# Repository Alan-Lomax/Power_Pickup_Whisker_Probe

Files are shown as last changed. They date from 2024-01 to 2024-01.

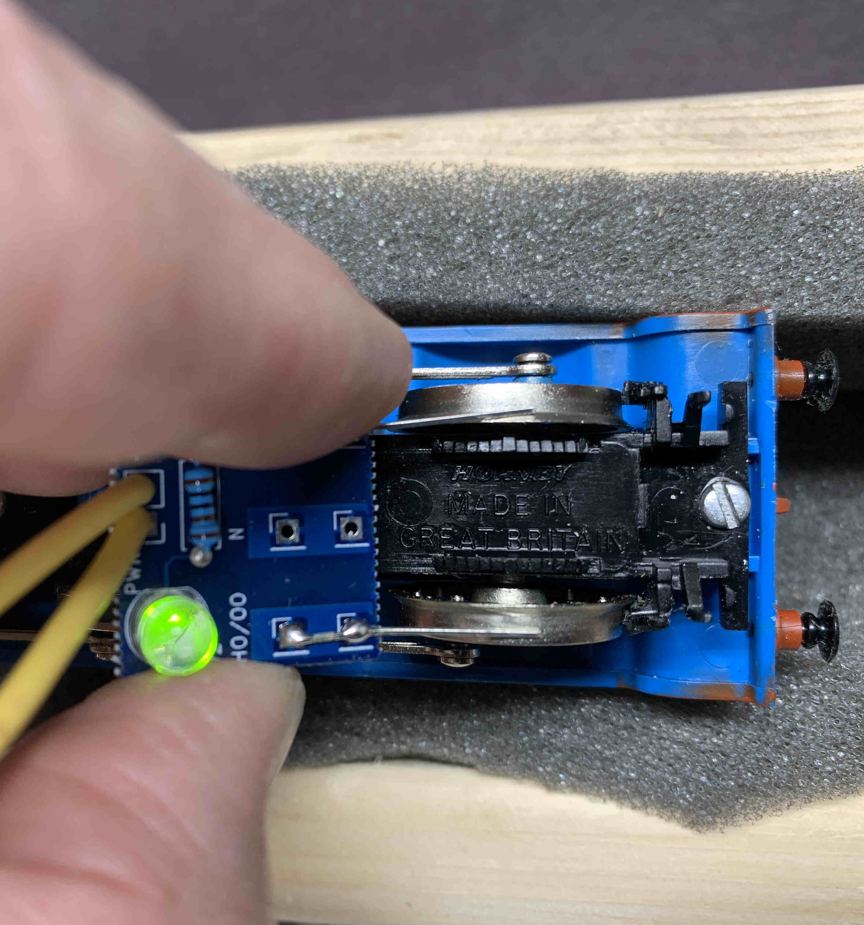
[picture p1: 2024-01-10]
Documentation/Photos/Figure 10f - Testing Pickups.jpg

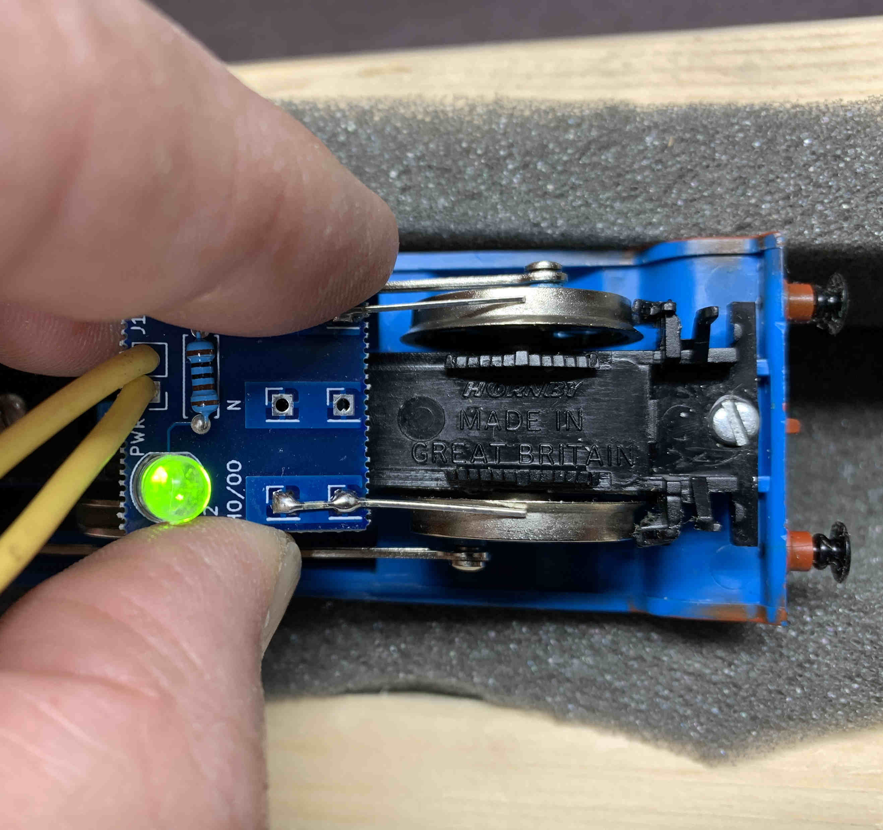
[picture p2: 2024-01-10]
Documentation/Photos/Figure 10e - Testing Pickups.jpg

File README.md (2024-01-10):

# Power Pickup Whisker Probe
Is a very small PCB board using only a couple of components (one LED and one resistor)
It is a simple voltage tester for use on the model railway.
Using the whiskers it can also be used to inject power to a specfic wheel set 
on a loco and thus used to detect loose, dirty, or ill fitting pickup contacts.

## Key Features
<Li>Reliable clear indication of power and polarity
<Li>Inexpensive and easy to build
<Li>DC or DCC operation
<Li>Test track, loco pickups, slow action DC motor switching

## Status of Development 
### Only one Prototype Version so Far

## Known Issues
<Li>None

## Thoughts for Improvement
<Li>Add a footprint for a terminal block

# The Panel Version
The PCB is sized less than 20mmm x 20 mm which means it can easily be panelized
in sets of 25. This makes the panelized PCB fit on a single 100mm x 100mm 
PCB which is the normal 'minimum size' for billing. 
Be Aware as the minimum board order quantity is 5 you would get 125 
Power Pickup Whisker Probe PCB's.

There is a seperate folder containing the Panelized version of the Gerbers.

As the individual PCB is small you could consider adding the 
Power Pickup Whisker Probe PCB to another PCB that you may be
ordering anyway.

# Be Aware
Normally all EDITS should be done to the 'single PCB' and then it be repanelized
To repanelize you start a new Kicad project (one with no contents)
and run a 'plug in' to panelize things. You will specfiy which other 
file has the PCB layout you want to panelize. 
You also set the number of rows (5) and collumns (5)
The only manual step needed is to add several straight edge to edge lines
(on the edge cut layer) to separate the individual test boards.
These will be intepreted as 'Vee-Cut' lines and allows separating the two PCBs easily.

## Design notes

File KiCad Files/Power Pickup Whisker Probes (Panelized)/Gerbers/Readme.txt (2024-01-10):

The panelized power pickup gerbers are a 5 x 5 array in 100mm x 100mm
With the minimum production qty of 5 PCB's that is 125 individual circuit boards
Boards have Vee Cut lines to make separation (de-panelizing) easier.

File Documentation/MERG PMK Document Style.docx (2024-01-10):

Potential Pocket Money Kit

January 2024

The Track Tester pocket money project PMP1 was first described, by Davy Dick, in the MERG Journal (2012 Vol 46 No. 3 p16-17). This kit while it was developed independently is similar but it also has whiskers for testing loco pickups.

Parts List

• PCB (Printed Circuit Board)

• One lead with a crocodile clip attached at each end

• One bi-colour LED

• One 1K resistor

There are many occasions when you may need to check if a particular section of track is receiving power.

Maybe -

• The power to a track section is switched by relays or switches.

• The wiring or connections to a piece of track is suspect.

• You want to check if you have wired a new piece of track with the polarity the

correct way round.

• You need to test if individual pickups on a Loco are working

• You need to test that a slow action point motor is getting power reversals as it should.

This simple PCB can do all of this with a minimum of parts. Of course, you could always check with a multimeter but these are inconvenient, bulky and awkward to use in tight situations.

With this little board, for rail checks you can use either the crocodile clips, the whiskers, or the contact points on the bottom of the PCB to illuminate the LED. If the LED lights Red or Green you have DC power with the colour indicating polarity. If the LED lights orange your track is receiving DCC power.

For testing loco pickups attach the crocodile leads to the track and touch the whiskers one to each wheel on a single axle. If the wheel pickups are working as they should be the loco motor will operate. You can then use the whiskers to apply side to side force in either direction to ensure pickups maintain contact with the wheels throughout the range of side-to-side motion. Repeat this on each axle that has pickups to give your loco a thorough checkup.

How it works

The circuit diagram is very simple. A bi-colour LED (light emitting diode) is connected across the track when the board's crocodile clips or the whiskers touch the rails. The 1k resistor is a current limiting resistor to ensure the track voltage does not result in excessive current that would destroy the LED. A bi-colour LED is simply two LEDs back-to-back and in the same LED package. So, if the track voltage is one polarity, the LED lights up in one colour (green for example), and if the track voltage is in the opposite polarity that same LED lights up a different colour (red for example). If the polarity is switching back and forth quickly (as in DCC) your eye perceives the blended colour.

Building Instructions

The components are inserted on the printed side of the PCB, and soldered on the other side. As there only a few parts strict order of assembly is not critical however the following sequence is recommended.

Fit the LED with the long lead inserted in the hole nearest the flats on the symbol. Note that with back-to-back diodes in the same package there is no ‘cathode lead’ or ‘anode lead’. The reason for setting the orientation is only to ensure the displayed colour shows consistently should you build several of these kits.

Ensure the LED is flush to the PCB and after soldering cut off both leads as close to the underside of the PCB as possible. IMPORTANT: We will be using the cut off leads as our whiskers in the next step.

Referring to Figure 6 use needle nose pliers put a 90 degree bend very close to one end in each lead. Insert the bent end into the PCB hole as indicated on the ‘Common’ set of pads. With the long end of the whisker roughly aligned solder the bent pin in place. Ensure the long end of the whisker lead goes over the center of the remaining hole (gently bending as needed) then solder the lead which is lying flat over the hole and extending past the edge of the board.

Depending on what gauge you are modelling (HO/OO or N) repeat this process for the second whisker using the appropriate set of holes.

Fit the resistor which can be inserted either way round.

Cut the crocodile lead in half, strip the ends of the “half leads” and solder them one at a time into the holes marked J1.

Lastly to avoid shorts if the board is laid on the track or other metalwork fit some insulation tape to one half of the back of the PCB (specifically under the resistor, LED and J1 part of the PCB. An alternative to tape is to apply hot glue from a glue gun.

Figures

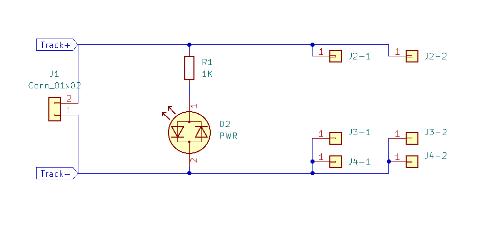
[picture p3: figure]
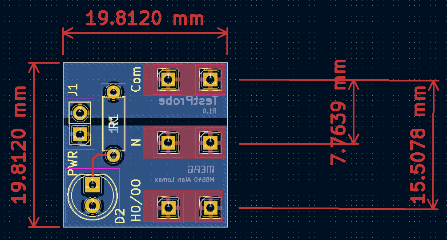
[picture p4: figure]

Figure 1: Schematic | Figure 2: Key Dimensions of PCB

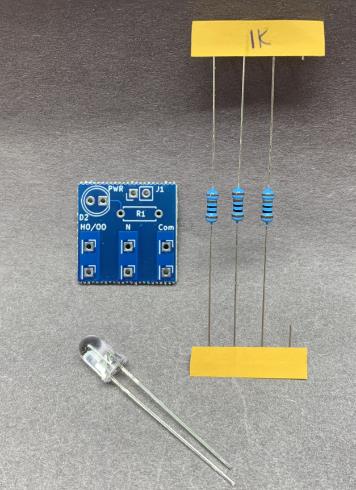
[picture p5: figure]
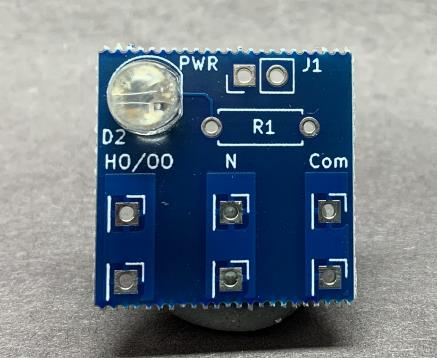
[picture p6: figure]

Figure 3: Key Parts (Only 1 Resistor needed of course) | Figure 4: LED Orientation LED oriented with Flat matching the symbol.

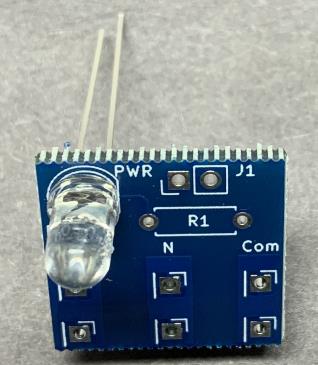
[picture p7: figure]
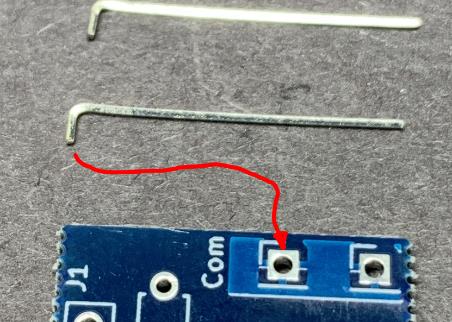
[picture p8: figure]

Figure 5: Showing the long lead is on the side with the Flat on a Bi-colour LED | Figure 6: First solder location of the first whisker

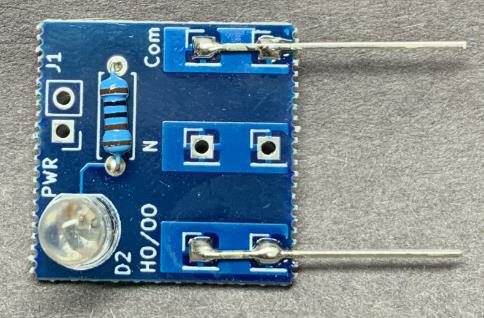
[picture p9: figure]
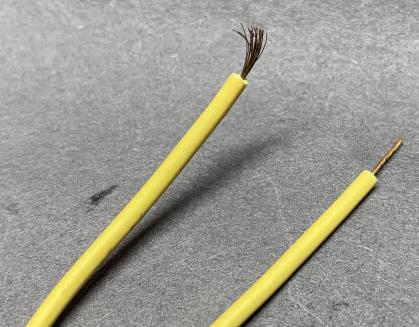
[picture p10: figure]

Figure 7: Whiskers aligned and Soldered, Components in Place | Figure 8: Leads stripped. A gentle twist of the strands (lower lead) makes inserting into the PCB easier and more importantly reduces the risk of an inadvertent short circuit from a stray strand.

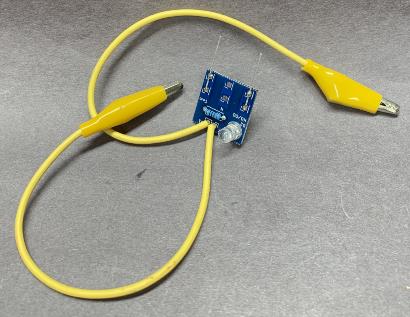
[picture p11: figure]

Figure 9: Fully Assembled and Ready to Use

# Usage Cases

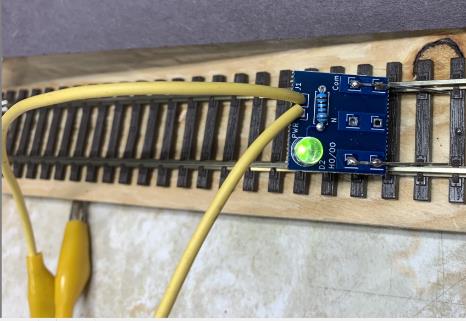
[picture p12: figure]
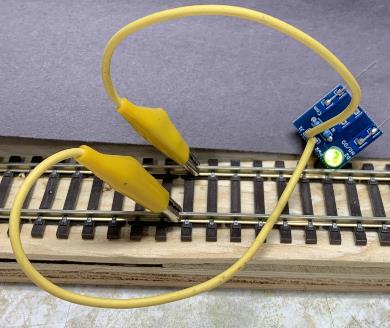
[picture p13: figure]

Figure 10a: Track power via the whiskers. Lower rail (The LED side) is positive green LED. | | Figure 10b: Alternate method using the crocodile clips.

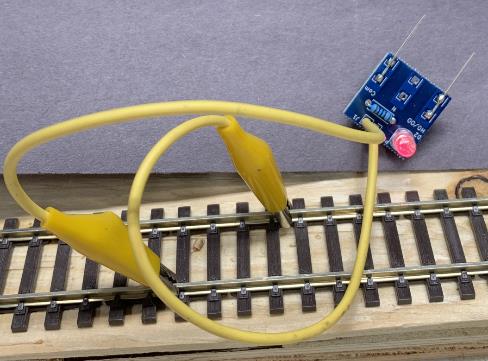
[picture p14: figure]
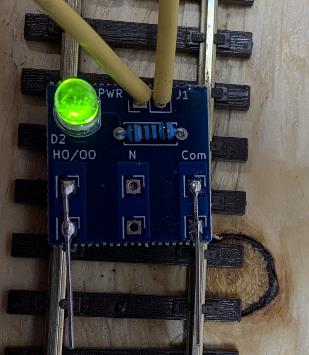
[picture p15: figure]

Figure 10c: Crocodile clips crossed over. Red LED indicates polarity is reversed (of course it is the leads that are actually reversed not the track voltage). | | Figure 10d: Alternate method – lay flat on the rails. Caution – Use only with whiskers in direction of track.

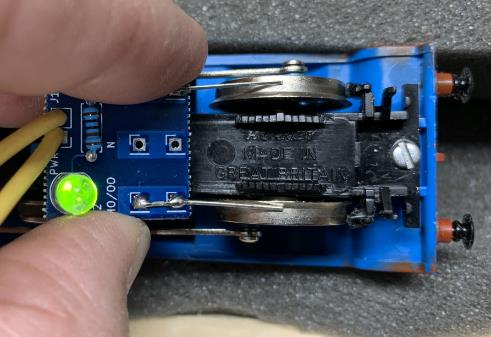
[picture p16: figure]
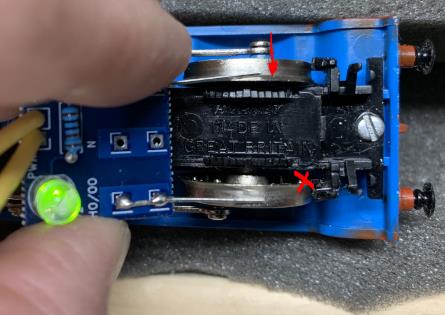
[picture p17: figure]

Figure 11a With crocodile clips on track use whiskers to apply power to a single wheel set. Wheels will turn if pickups are working correctly. Lateral force up on the lower flange reveals if the pickup on the upper wheel is breaking contact. As the motor keeps running these pickups are operating as expected. | Figure 11b Lateral force down opens up the gap as shown by X. The motor stops running but the LED indicates I still have power. The pickups on the side marked X need a slight adjustment.

Ideas for Variations:

It may be desirable in some situations to use terminal blocks instead of directly soldering the crocodile clips in place. At the moment the spacing of the PCB holes does not accommodate dropping in a terminal block so some customization will be required.

Using the LED leads for whiskers may not allow for enough lateral force for your application. It is possible to substitute 0.8 mm stainless steel piano wire (two pieces each 2 cm long). Note however that soldering of stainless steel requires a fit for purpose acid flux applied to the piano wire (at the end with the 90-degree bend plus half the remaining length). This much of the whisker is then tinned with solder. The flux must be cleaned off thoroughly before the whiskers are installed on the PCB. (If not the Acid could continue to work away potentially damaging the board)

Acknowledgements

Mike Walton of the Platelayers MRC in Ontario Canada who patiently explained his ‘snag report’ and the home-made whisker set up that he came up with to find that pesky loco pickup that only failed in a certain location of his layout.

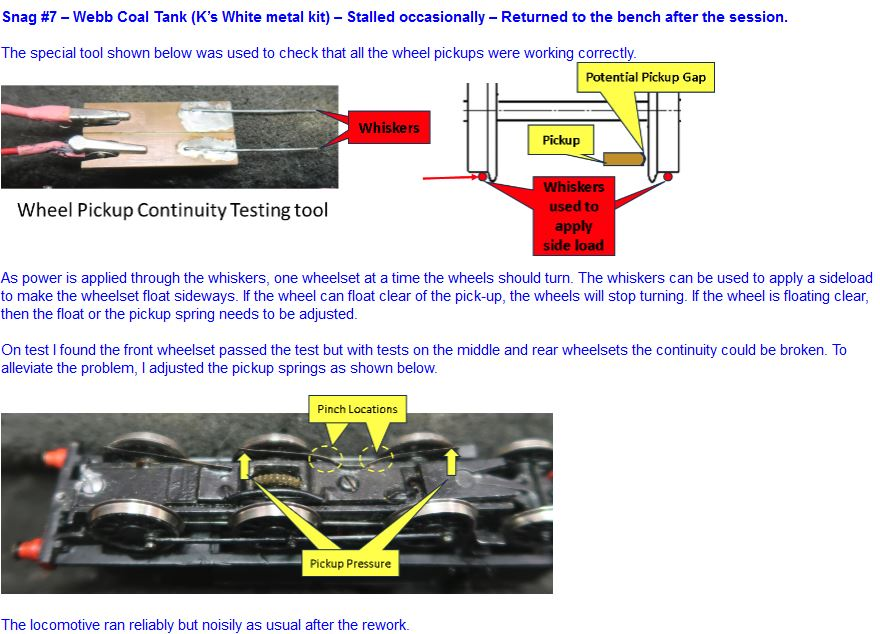
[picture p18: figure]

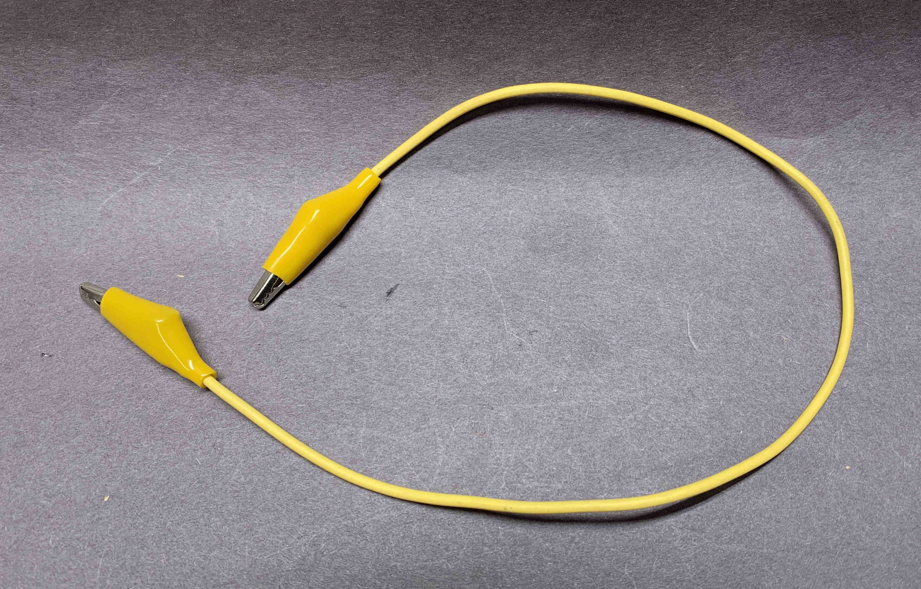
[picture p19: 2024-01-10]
Documentation/Photos/Figure 4 Single Alligator Clip.jpg

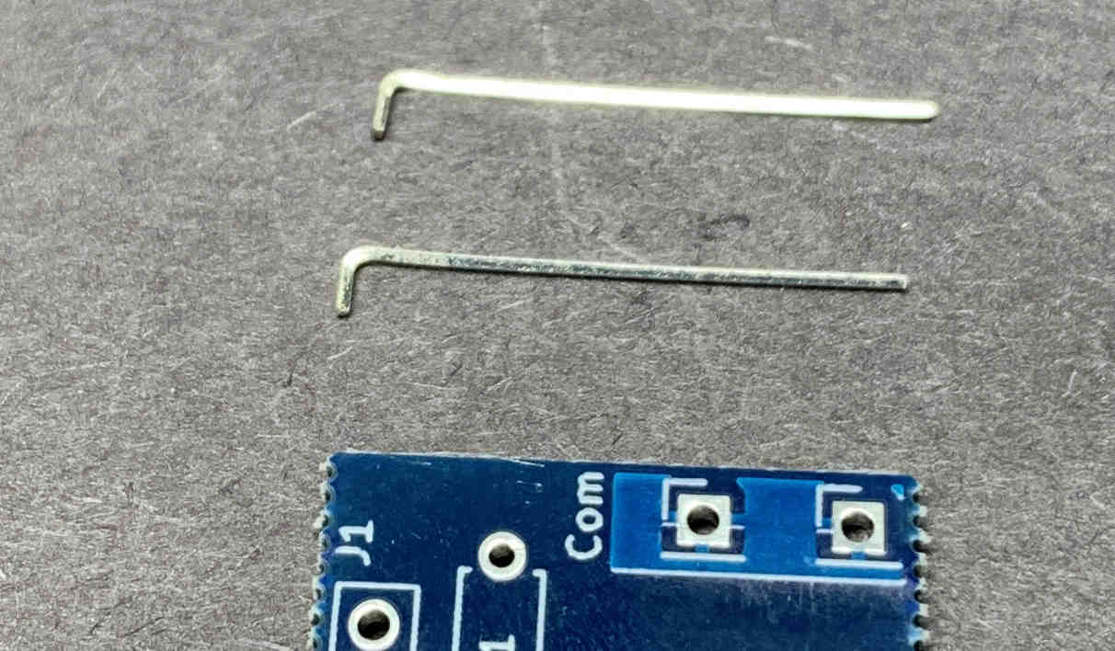
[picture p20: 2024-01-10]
Documentation/Photos/Figure 6 LED leads cutoff trimmed and bent.jpg

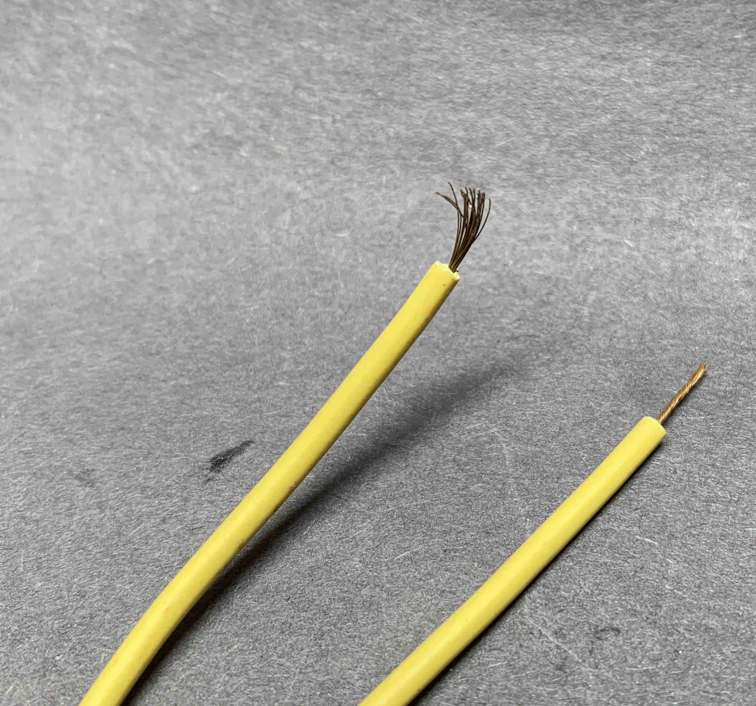
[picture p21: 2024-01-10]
Documentation/Photos/Figure 8 Importance of Twisting the ends.jpg

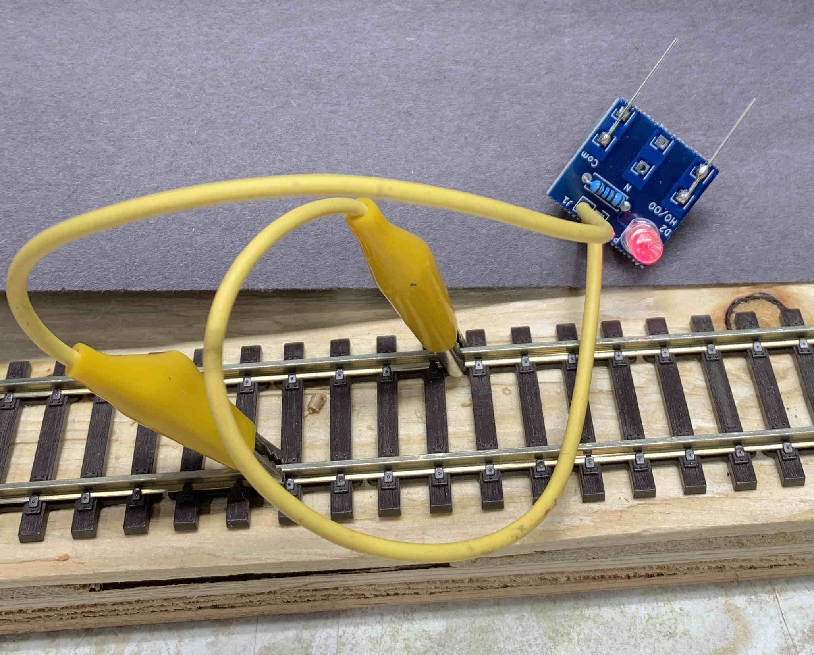
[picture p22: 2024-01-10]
Documentation/Photos/Figure 10c - Track Power.jpg

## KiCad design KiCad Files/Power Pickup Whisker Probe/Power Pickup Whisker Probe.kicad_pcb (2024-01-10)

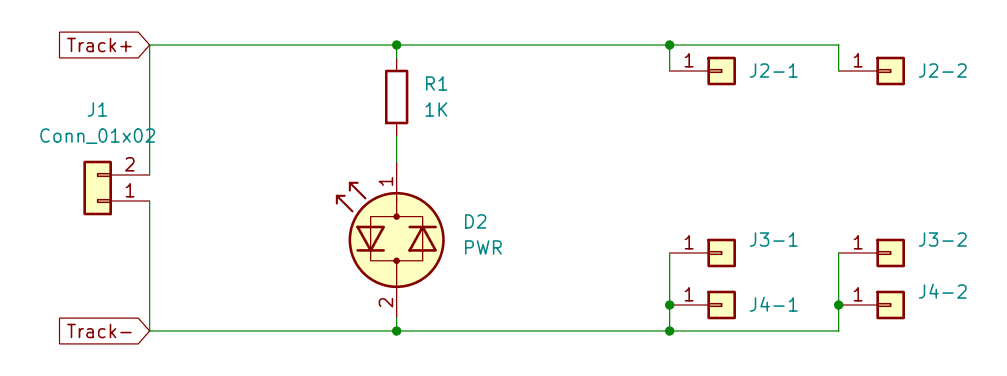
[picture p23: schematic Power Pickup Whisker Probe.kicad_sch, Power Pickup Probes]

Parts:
D2: PWR; LED_D5.0mm
J1: Conn_01x02; PinHeader_1x02_P2.54mm_Vertical
J2-1: Com; PinHeader_1x01_P2.54mm_Vertical
J2-2, J3-2, J4-2: Conn_01x01; PinHeader_1x01_P2.54mm_Vertical
J3-1: N; PinHeader_1x01_P2.54mm_Vertical
J4-1: HO/OO; PinHeader_1x01_P2.54mm_Vertical
R1: 1K; R_Axial_DIN0207_L6.3mm_D2.5mm_P7.62mm_Horizontal

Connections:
unnamed: D2.1 (KA), R1.2
Track+: J1.2, J2-1.1, J2-2.1, R1.1
Track-: D2.2 (AK), J1.1, J3-1.1, J3-2.1, J4-1.1, J4-2.1

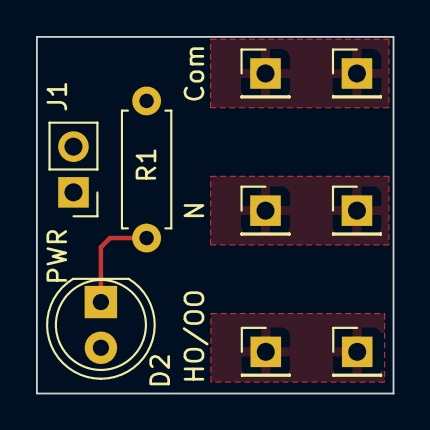
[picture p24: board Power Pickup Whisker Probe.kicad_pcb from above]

Board: 2 copper layers, 19.8 x 19.8 mm, 9 parts (0 on the bottom side), 3 nets.
